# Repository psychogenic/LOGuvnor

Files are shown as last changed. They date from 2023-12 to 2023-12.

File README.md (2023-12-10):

# LO Guv'nor: Si5351 clock generators for the workbench

Copyright (C) 2023  Pat Deegan.  All rights reserved.

[https://psychogenic.com](https://psychogenic.com)

Source code is released under the GPL (see code/LICENSE), hardware resources under CC BY-SA 4.0 (see hardware/LICENSE)

This is a very simple way to transform the widely used Si5351 modules into a useful lab/workbench tool. The entire purpose is to get access to these three clock generators--which can provide clocks in the low kiloHertz up to hundreds of MegaHertz--with minimal interruption to your workflow.
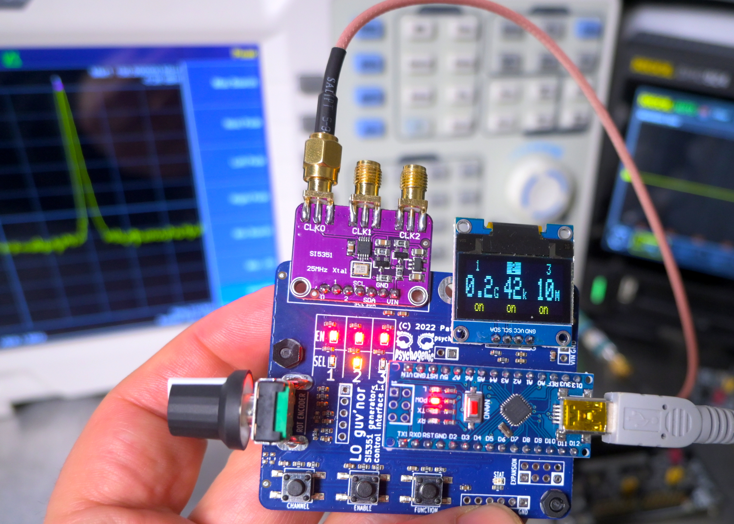
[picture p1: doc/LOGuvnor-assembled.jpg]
LO Guv'nor


A rotary encoder, an OLED display, and a few momentary switches are all glued together through this basic PCB and bundled with a Nano and the code that provides a quick, and hackable, user interface to the clock generator.

This can be used to prototype Si5351 chip/module use, of course, but is mainly meant to provide mid-range clock signals for driving prototypes and tests. Less capable that a true signal generator--it only outputs square waves--but it offers coverage of a wide band of frequency ranges that go beyond what typical (read: inexpensive) function generators can handle.

Most of the intelligence and function of the system resides in the software, which is a bit more involved than the glue hardware.  Full walk-through video, covering the simple hardware, but diving deep into the software created, should be available by December 11th on [youtube](https://youtu.be/oYbZDdBwuf4)

Nothing complex about the schematic, which is little more than
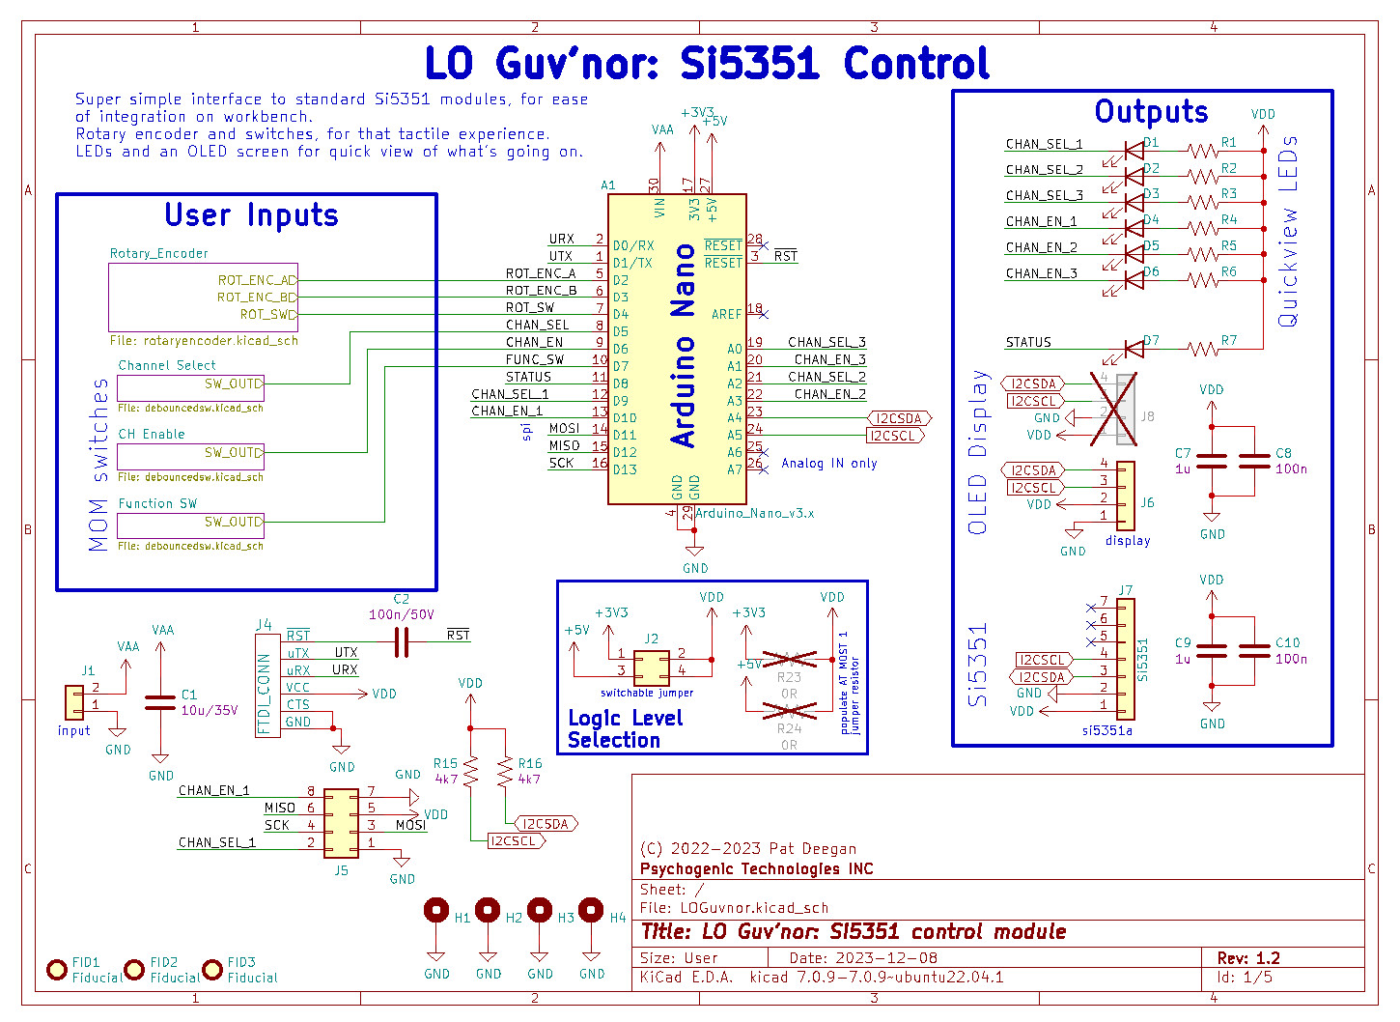
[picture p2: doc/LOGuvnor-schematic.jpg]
LO Guv'nor schematic


The full schema may be found in the [schematic PDF](https://raw.githubusercontent.com/psychogenic/LOGuvnor/main/doc/LOGuvnor-schematic.pdf)

This version of the boards includes some fixes and additional features, which will be covered in future online documentation and video.

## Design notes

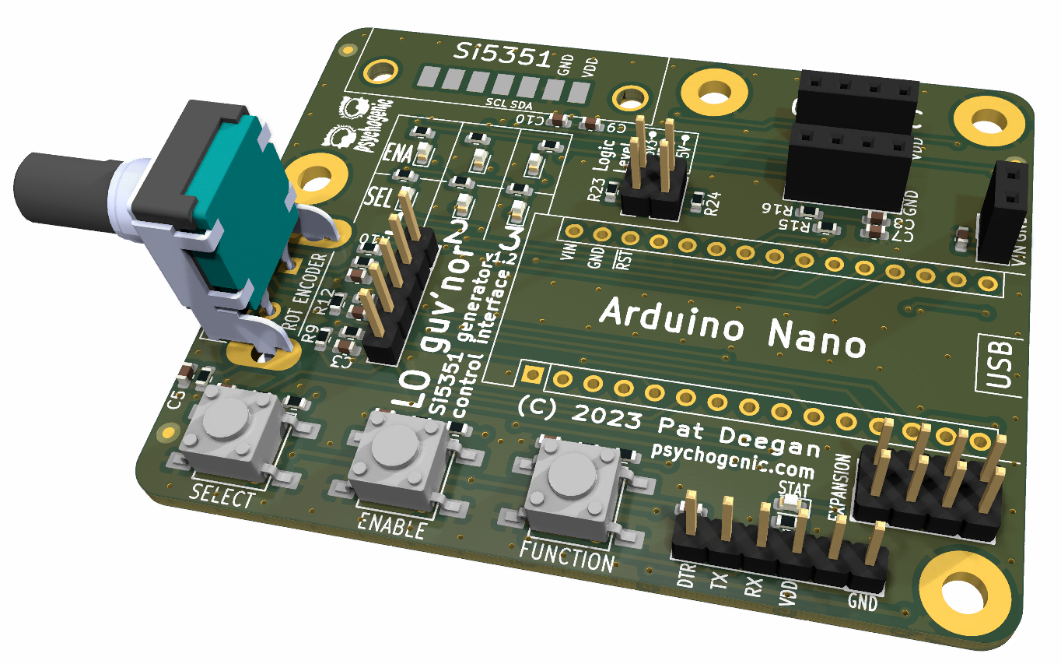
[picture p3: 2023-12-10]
doc/LOGuvnor-PCB.png

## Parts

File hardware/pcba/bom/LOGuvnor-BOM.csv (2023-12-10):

Item | Qty | Reference | DNP | Value | Footprint | Display Value | MPN | Digikey PN
Source: | LOGuvnor/LOGuvnor.kicad_sch
Date: | Sun 10 Dec 2023 03:40:18 AM
Tool: | Eeschema 7.0.9-7.0.9~ubuntu22.04.1
Component Count: | 57
Individual Components:
Item | Qty | Reference | DNP | Value | Footprint | Display Value | MPN | Digikey PN
 |  | A1 |  | Arduino_Nano_v3.x | Module:Arduino_Nano
 |  | C1 |  | C_10u_0603_35V | Capacitor_SMD:C_0603_1608Metric | 10u/35V | GRM188R6YA106MA73D | 490-13248-1-ND
 |  | C2 |  | C_100n_0603_50V | Capacitor_SMD:C_0603_1608Metric | 100n/50V | GCJ188R71H104KA12D | 490-5798-1-ND
 |  | C3 |  | C_100n_0603_50V | Capacitor_SMD:C_0603_1608Metric | 100n/50V | GCJ188R71H104KA12D | 490-5798-1-ND
 |  | C4 |  | C_100n_0603_50V | Capacitor_SMD:C_0603_1608Metric | 100n/50V | GCJ188R71H104KA12D | 490-5798-1-ND
 |  | C5 | DNP | C_10n_0603_100V | Capacitor_SMD:C_0603_1608Metric | 10n/100V | GCM188R72A103KA37J | 490-8028-1-ND
 |  | C6 |  | C_100n_0603_50V | Capacitor_SMD:C_0603_1608Metric | 100n/50V | GCJ188R71H104KA12D | 490-5798-1-ND
 |  | C7 |  | C_1u_0603_50V | Capacitor_SMD:C_0603_1608Metric | 1u | GRT188R61H105KE13D | 490-12330-1-ND
 |  | C8 |  | C_100n_0603_50V | Capacitor_SMD:C_0603_1608Metric | 100n | GCJ188R71H104KA12D | 490-5798-1-ND
 |  | C9 |  | C_1u_0603_50V | Capacitor_SMD:C_0603_1608Metric | 1u | GRT188R61H105KE13D | 490-12330-1-ND
 |  | C10 |  | C_100n_0603_50V | Capacitor_SMD:C_0603_1608Metric | 100n | GCJ188R71H104KA12D | 490-5798-1-ND
 |  | C11 |  | C_100n_0603_50V | Capacitor_SMD:C_0603_1608Metric | 100n/50V | GCJ188R71H104KA12D | 490-5798-1-ND
 |  | C12 |  | C_100n_0603_50V | Capacitor_SMD:C_0603_1608Metric | 100n/50V | GCJ188R71H104KA12D | 490-5798-1-ND
 |  | C13 |  | C_100n_0603_50V | Capacitor_SMD:C_0603_1608Metric | 100n/50V | GCJ188R71H104KA12D | 490-5798-1-ND
 |  | D1 |  | LED | LED_SMD:LED_0603_1608Metric
 |  | D2 |  | LED | LED_SMD:LED_0603_1608Metric
 |  | D3 |  | LED | LED_SMD:LED_0603_1608Metric
 |  | D4 |  | LED | LED_SMD:LED_0603_1608Metric
 |  | D5 |  | LED | LED_SMD:LED_0603_1608Metric
 |  | D6 |  | LED | LED_SMD:LED_0603_1608Metric
 |  | D7 |  | LED | LED_SMD:LED_0603_1608Metric
 |  | J1 |  | Conn_01x02 | Connector_PinSocket_2.54mm:PinSocket_1x02_P2.54mm_Vertical
 |  | J2 |  | Conn_02x02_Odd_Even | Connector_PinHeader_2.54mm:PinHeader_2x02_P2.54mm_Vertical
 |  | J3 | DNP | Conn_01x05 | Connector_PinHeader_2.54mm:PinHeader_1x05_P2.54mm_Vertical
 |  | J4 |  | FTDI_CONN | Connector_PinHeader_2.54mm:PinHeader_1x06_P2.54mm_Vertical
 |  | J5 |  | Conn_02x04_Odd_Even | Connector_PinHeader_2.54mm:PinHeader_2x04_P2.54mm_Vertical
 |  | J6 |  | Conn_01x04 | Connector_PinSocket_2.54mm:PinSocket_1x04_P2.54mm_Vertical
 |  | J7 |  | Si5351 | psychogenic:Si5351aModule
 |  | J8 | DNP | Conn_01x04 | Connector_PinSocket_2.54mm:PinSocket_1x04_P2.54mm_Vertical
 |  | R1 |  | R_1k_0603 | Resistor_SMD:R_0603_1608Metric | 1k | CRGP0603F1K0 | A130416CT-ND
 |  | R2 |  | R_1k_0603 | Resistor_SMD:R_0603_1608Metric | 1k | CRGP0603F1K0 | A130416CT-ND
 |  | R3 |  | R_1k_0603 | Resistor_SMD:R_0603_1608Metric | 1k | CRGP0603F1K0 | A130416CT-ND
 |  | R4 |  | R_1k_0603 | Resistor_SMD:R_0603_1608Metric | 1k | CRGP0603F1K0 | A130416CT-ND
 |  | R5 |  | R_1k_0603 | Resistor_SMD:R_0603_1608Metric | 1k | CRGP0603F1K0 | A130416CT-ND
 |  | R6 |  | R_1k_0603 | Resistor_SMD:R_0603_1608Metric | 1k | CRGP0603F1K0 | A130416CT-ND
 |  | R7 |  | R_1k_0603 | Resistor_SMD:R_0603_1608Metric | 1k | CRGP0603F1K0 | A130416CT-ND
 |  | R8 |  | R_10k_0603 | Resistor_SMD:R_0603_1608Metric | 10k | CRGP0603F10K | A130428CT-ND
 |  | R9 |  | R_10k_0603 | Resistor_SMD:R_0603_1608Metric | 10k | CRGP0603F10K | A130428CT-ND
 |  | R10 |  | R_10k_0603 | Resistor_SMD:R_0603_1608Metric | 10k | CRGP0603F10K | A130428CT-ND
 |  | R11 |  | R_1k_0603 | Resistor_SMD:R_0603_1608Metric | 1k | CRGP0603F1K0 | A130416CT-ND
 |  | R12 |  | R_10k_0603 | Resistor_SMD:R_0603_1608Metric | 10k | CRGP0603F10K | A130428CT-ND
 |  | R13 |  | R_10k_0603 | Resistor_SMD:R_0603_1608Metric | 10k | CRGP0603F10K | A130428CT-ND
 |  | R14 | DNP | R_1M_0603 | Resistor_SMD:R_0603_1608Metric | 1M | CRGCQ0603F1M0 | A129724CT-ND
 |  | R15 |  | R_4k7_0603 | Resistor_SMD:R_0603_1608Metric | 4k7 | CRGP0603F4K7 | A130424DKR-ND
 |  | R16 |  | R_4k7_0603 | Resistor_SMD:R_0603_1608Metric | 4k7 | CRGP0603F4K7 | A130424DKR-ND
 |  | R17 |  | R_10k_0603 | Resistor_SMD:R_0603_1608Metric | 10k | CRGP0603F10K | A130428CT-ND
 |  | R18 |  | R_1k_0603 | Resistor_SMD:R_0603_1608Metric | 1k | CRGP0603F1K0 | A130416CT-ND
 |  | R19 |  | R_10k_0603 | Resistor_SMD:R_0603_1608Metric | 10k | CRGP0603F10K | A130428CT-ND
 |  | R20 |  | R_1k_0603 | Resistor_SMD:R_0603_1608Metric | 1k | CRGP0603F1K0 | A130416CT-ND
 |  | R21 |  | R_10k_0603 | Resistor_SMD:R_0603_1608Metric | 10k | CRGP0603F10K | A130428CT-ND
 |  | R22 |  | R_1k_0603 | Resistor_SMD:R_0603_1608Metric | 1k | CRGP0603F1K0 | A130416CT-ND
 |  | R23 | DNP | R_0R_0603_JUMPER | Resistor_SMD:R_0603_1608Metric | 0R | CRG0603ZR | A106051CT-ND
 |  | R24 | DNP | R_0R_0603_JUMPER | Resistor_SMD:R_0603_1608Metric | 0R | CRG0603ZR | A106051CT-ND
 |  | S1 |  | PEC12R-2220F-S0024 | psysnapeda:XDCR_PEC12R-2220F-S0024 |  | PEC12R-2220F-S0024 | PEC12R-2220F-S0024-ND
 |  | SW1 |  | SW_Push_6x6 | flyingcarsfootprints:FSM2JSMA-6x6mm-SWITCH | SW_Push | FSM2JSMA | 450-1130-ND
 |  | SW2 |  | SW_Push_6x6 | flyingcarsfootprints:FSM2JSMA-6x6mm-SWITCH | SW_Push | FSM2JSMA | 450-1130-ND
 |  | SW3 |  | SW_Push_6x6 | flyingcarsfootprints:FSM2JSMA-6x6mm-SWITCH | SW_Push | FSM2JSMA | 450-1130-ND
Collated Components:
Item | Qty | Reference | DNP | Value | Footprint | Display Value | MPN | Digikey PN
1 | 1 | A1 | 0 | Arduino_Nano_v3.x | Module:Arduino_Nano
2 | 1 | C1 | 0 | C_10u_0603_35V | Capacitor_SMD:C_0603_1608Metric | 10u/35V | GRM188R6YA106MA73D | 490-13248-1-ND
3 | 9 | C2,C3,C4,C6,C8,C10,C11,C12,C13 | 0 | C_100n_0603_50V | Capacitor_SMD:C_0603_1608Metric | 100n/50V | GCJ188R71H104KA12D | 490-5798-1-ND
4 | 0 | C5 | DNPs: all DNP, final qty: 0 | C_10n_0603_100V | Capacitor_SMD:C_0603_1608Metric | 10n/100V | GCM188R72A103KA37J | 490-8028-1-ND
5 | 2 | C7,C9 | 0 | C_1u_0603_50V | Capacitor_SMD:C_0603_1608Metric | 1u | GRT188R61H105KE13D | 490-12330-1-ND
6 | 7 | D1,D2,D3,D4,D5,D6,D7 | 0 | LED | LED_SMD:LED_0603_1608Metric
7 | 1 | J1 | 0 | Conn_01x02 | Connector_PinSocket_2.54mm:PinSocket_1x02_P2.54mm_Vertical
8 | 1 | J2 | 0 | Conn_02x02_Odd_Even | Connector_PinHeader_2.54mm:PinHeader_2x02_P2.54mm_Vertical
9 | 0 | J3 | DNPs: all DNP, final qty: 0 | Conn_01x05 | Connector_PinHeader_2.54mm:PinHeader_1x05_P2.54mm_Vertical
10 | 1 | J4 | 0 | FTDI_CONN | Connector_PinHeader_2.54mm:PinHeader_1x06_P2.54mm_Vertical
11 | 1 | J5 | 0 | Conn_02x04_Odd_Even | Connector_PinHeader_2.54mm:PinHeader_2x04_P2.54mm_Vertical
12 | 1 | J6,J8 | DNPs: 1 (final qty: 1): J8 | Conn_01x04 | Connector_PinSocket_2.54mm:PinSocket_1x04_P2.54mm_Vertical
13 | 1 | J7 | 0 | Si5351 | psychogenic:Si5351aModule
14 | 11 | R1,R2,R3,R4,R5,R6,R7,R11,R18,R20,R22 | 0 | R_1k_0603 | Resistor_SMD:R_0603_1608Metric | 1k | CRGP0603F1K0 | A130416CT-ND
15 | 8 | R8,R9,R10,R12,R13,R17,R19,R21 | 0 | R_10k_0603 | Resistor_SMD:R_0603_1608Metric | 10k | CRGP0603F10K | A130428CT-ND
16 | 0 | R14 | DNPs: all DNP, final qty: 0 | R_1M_0603 | Resistor_SMD:R_0603_1608Metric | 1M | CRGCQ0603F1M0 | A129724CT-ND
17 | 2 | R15,R16 | 0 | R_4k7_0603 | Resistor_SMD:R_0603_1608Metric | 4k7 | CRGP0603F4K7 | A130424DKR-ND
18 | 0 | R23,R24 | DNPs: all DNP, final qty: 0 | R_0R_0603_JUMPER | Resistor_SMD:R_0603_1608Metric | 0R | CRG0603ZR | A106051CT-ND
19 | 1 | S1 | 0 | PEC12R-2220F-S0024 | psysnapeda:XDCR_PEC12R-2220F-S0024 |  | PEC12R-2220F-S0024 | PEC12R-2220F-S0024-ND
20 | 3 | SW1,SW2,SW3 | 0 | SW_Push_6x6 | flyingcarsfootprints:FSM2JSMA-6x6mm-SWITCH | SW_Push | FSM2JSMA | 450-1130-ND

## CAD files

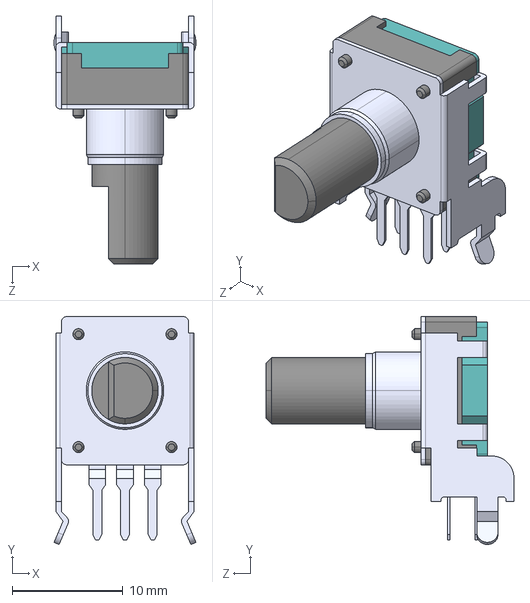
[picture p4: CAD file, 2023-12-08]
hardware/3dmodels/PEC12R-2220F-S0024.step
12.8 x 20.6 x 22.4 mm

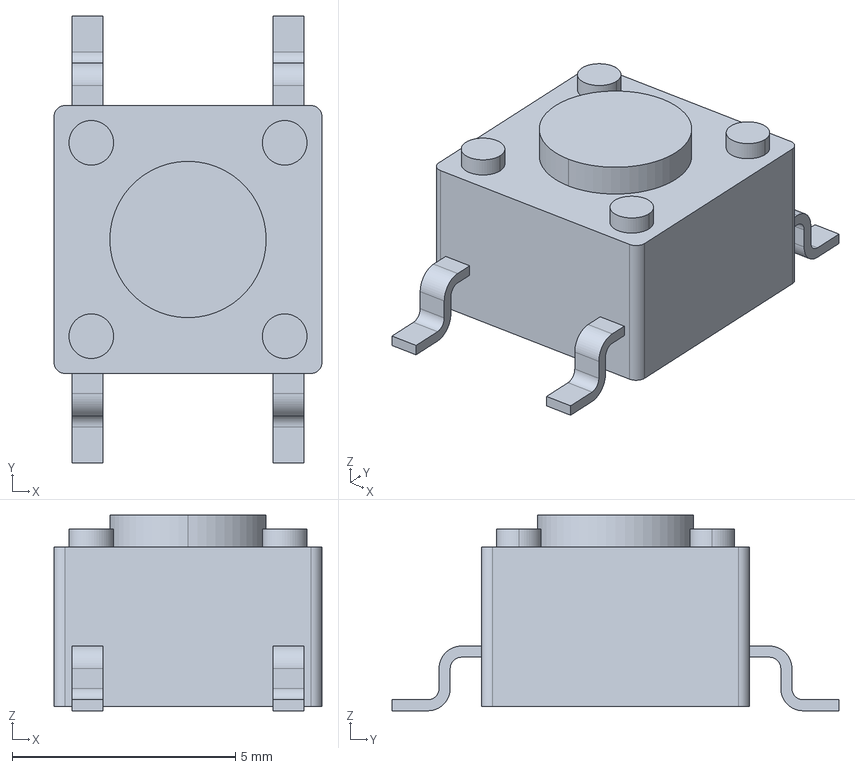
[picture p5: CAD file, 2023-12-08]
hardware/3dmodels/FSM2JSMA.step
6.00 x 10.0 x 4.38 mm

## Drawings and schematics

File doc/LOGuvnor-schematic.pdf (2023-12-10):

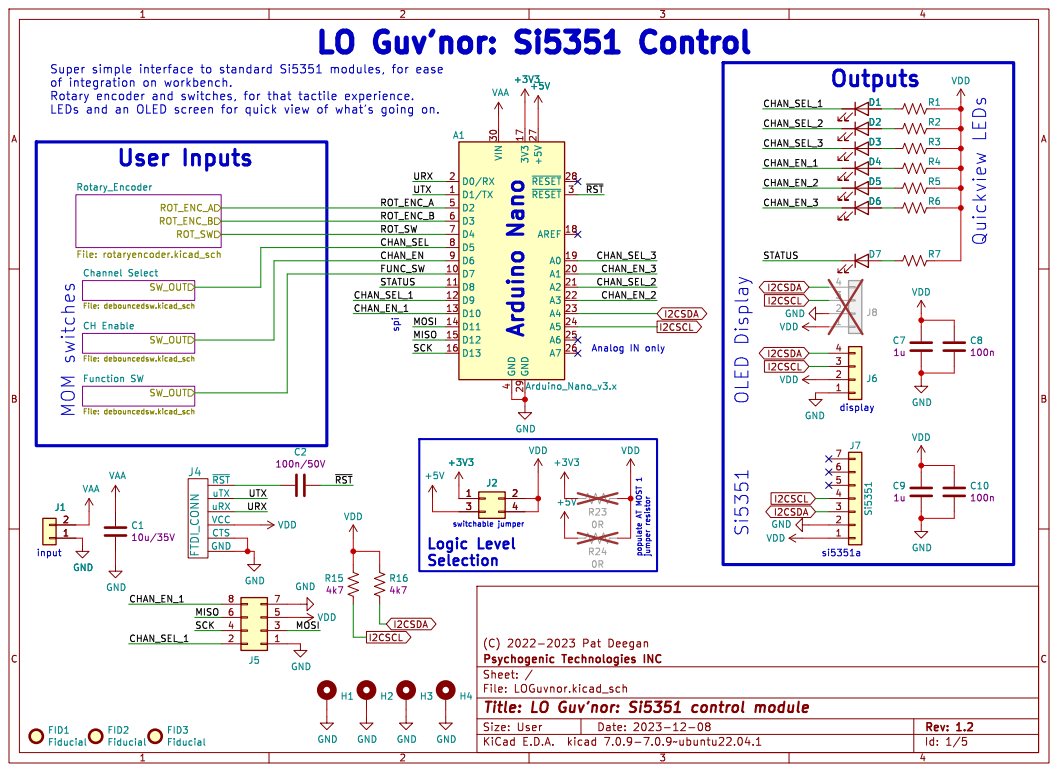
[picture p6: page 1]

+5V +3V3 GND
LEDs and an OLED screen for quick view of what's going on.

of integration on workbench.

File: debouncedsw.kicad_sch SW_OUT CH Enable

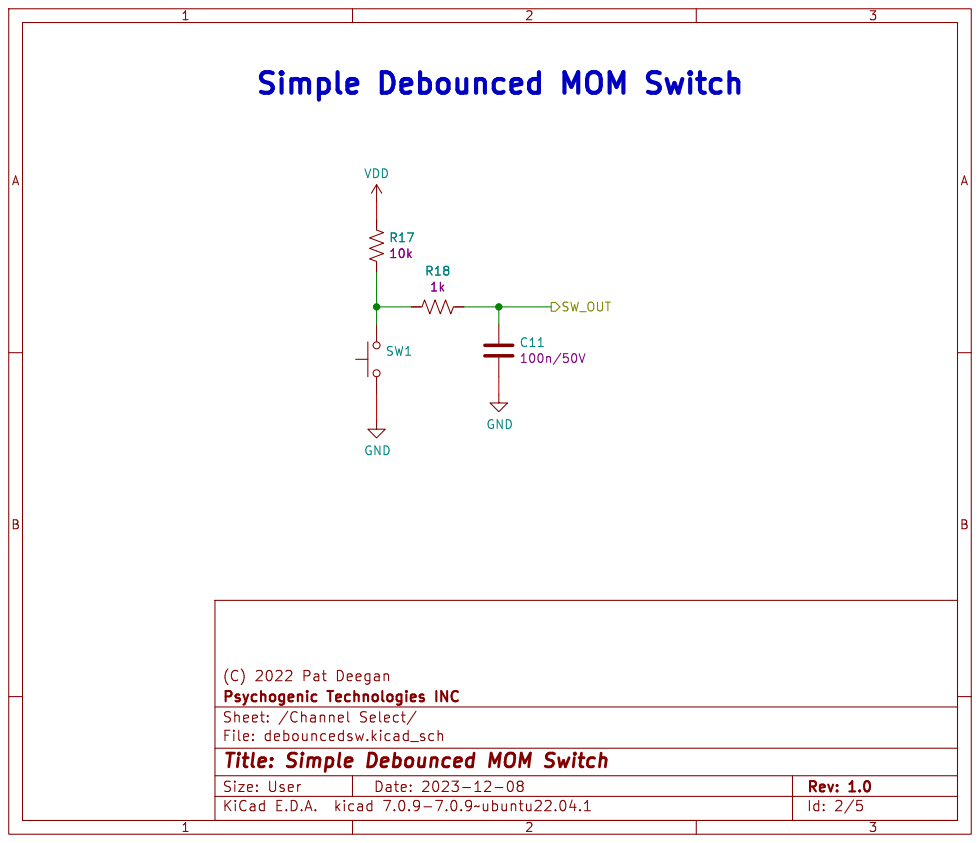
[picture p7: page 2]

Id: 2/5 Title: Simple Debounced MOM Switch

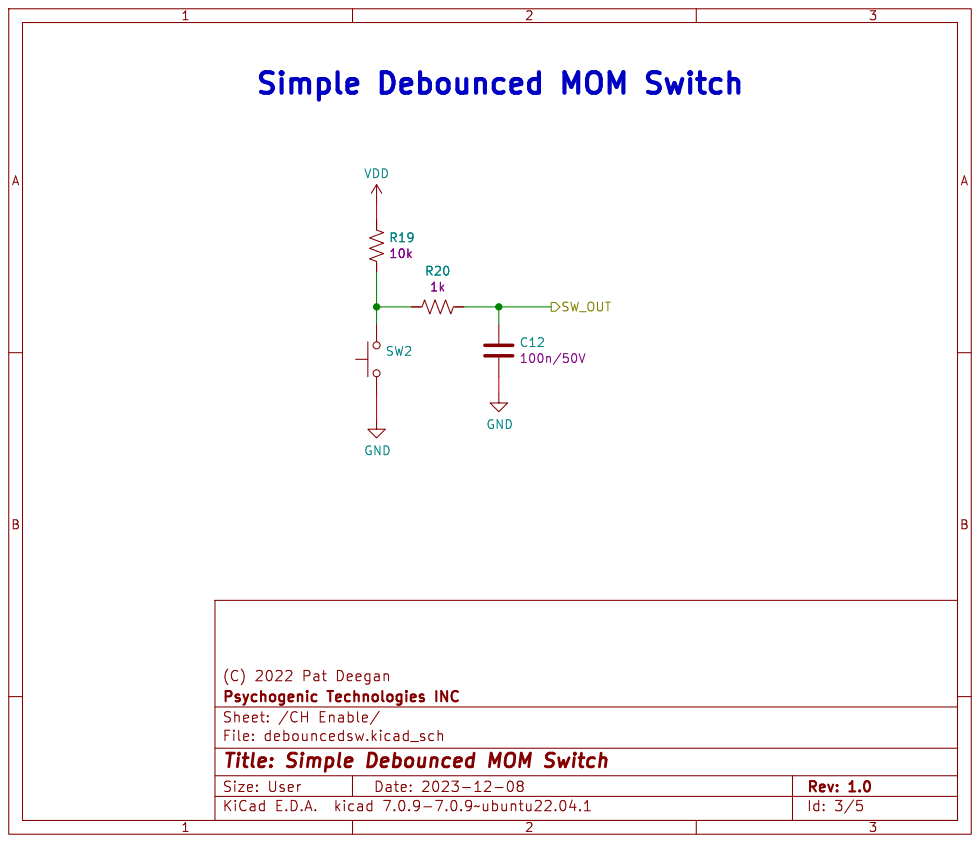
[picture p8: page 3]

Id: 3/5 Title: Simple Debounced MOM Switch

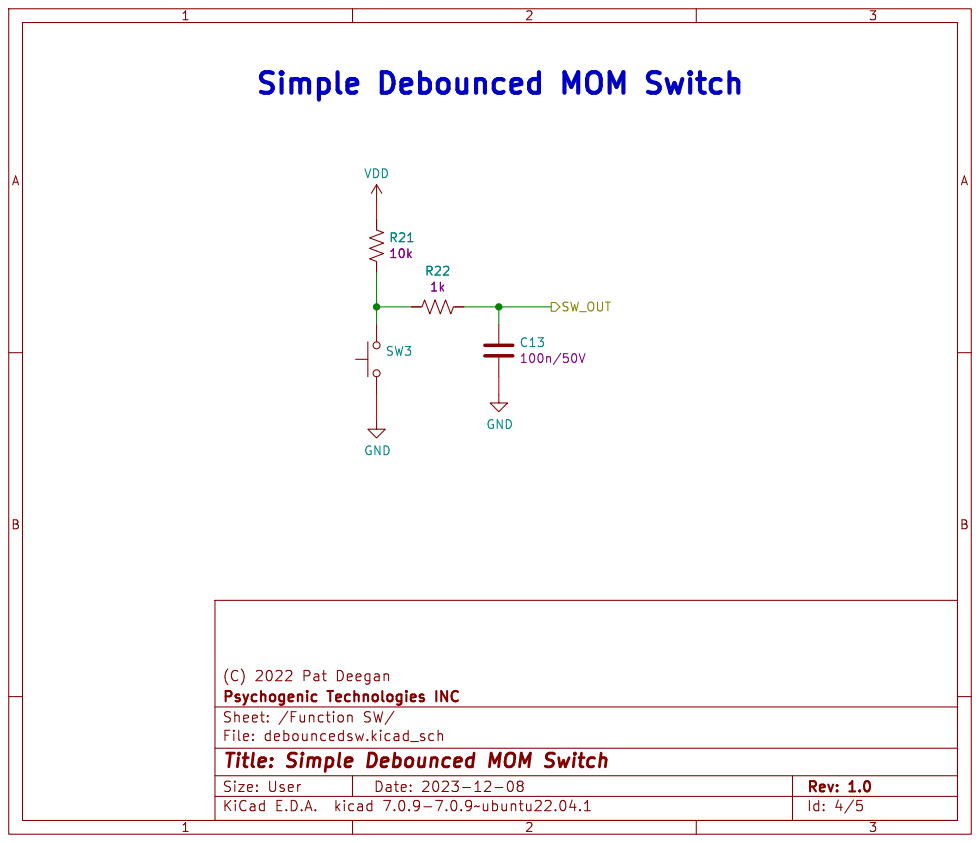
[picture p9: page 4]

Id: 4/5 Title: Simple Debounced MOM Switch

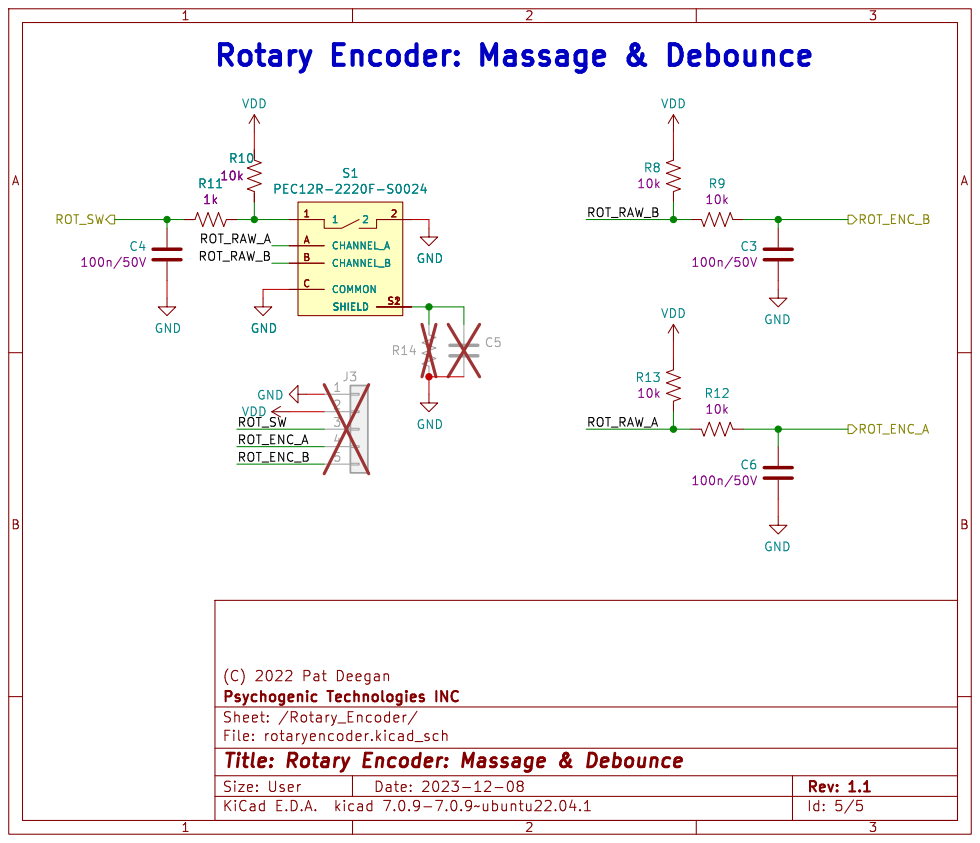
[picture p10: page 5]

File: rotaryencoder.kicad_sch Sheet: /Rotary_Encoder/
Id: 5/5 Title: Rotary Encoder: Massage & Debounce

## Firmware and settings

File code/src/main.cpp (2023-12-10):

/*
 * LOGuvnorDriver.ino, part of the LOGuvnor project
 *
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
 *  This is the main driver for the LOGuvnor library.
 *
 *  It's only jobs are to:
 *    * setup the various pins in use (as inputs outputs etc)
 *    * construct the rotary encoder object used and set that up
 *    * init the library Driver object
 *    * loop around, noticing if knob was turned (and telling the world) and ticking driver
 *
 * The end.
 *
 *
 */



#ifdef DESKTOP_BUILD2
/*
 * LOGuvnorDriver.ino, part of the LOGuvnor project
 *
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
 *  This is the main driver for the LOGuvnor library.
 *
 *  It's only jobs are to:
 *    * setup the various pins in use (as inputs outputs etc)
 *    * construct the rotary encoder object used and set that up
 *    * init the library Driver object
 *    * loop around, noticing if knob was turned (and telling the world) and ticking driver
 *
 * The end.
 *
 *
 */

#include <LOGuvnor.h>
#include <RotaryEncoder.h>



/* *** Rotary encoder stuff... *** */

// create the instance
// use TWO03 mode when A and B signals are both LOW or HIGH in latch position.
RotaryEncoder rotEnc(PIN_ROTENC_A, PIN_ROTENC_B, RotaryEncoder::LatchMode::FOUR3);

// give it an ISR and flag
volatile bool checkRotaryEncoder = false;
void checkPosition()
{
  rotEnc.tick(); // just call tick() to check the state.
  checkRotaryEncoder = true;
}



/* *** setup *** */
void setup() {
	uint8_t inputs[] = {
			PIN_ROTENC_A,
			PIN_ROTENC_B,
			PIN_ROTSWITCH,
			PIN_SW_CHANSEL,
			PIN_SW_CHANEN,
			PIN_SW_FUNCTION,
			0xff
	};
	uint8_t outputs[] = {
			PIN_STATUS,
			PIN_INDIC_nCHANSEL_1,
			PIN_INDIC_nCHANENA_1,
			PIN_INDIC_nCHANSEL_2,
			PIN_INDIC_nCHANENA_2,
			PIN_INDIC_nCHANSEL_3,
			PIN_INDIC_nCHANENA_3,
			0xff
	};


	uint8_t i=0;
	while (inputs[i] != 0xff) {
		pinMode(inputs[i], INPUT); //_PULLUP);
		i++;
	}
	i=0;
	while (outputs[i] != 0xff) {
		pinMode(outputs[i], OUTPUT);
		digitalWrite(outputs[i], HIGH);
    i++;
	}

/*
  for (uint8_t i=0; i<10; i++) {

    digitalWrite(PIN_INDIC_nCHANENA_1, HIGH);
    delay(200);
    digitalWrite(PIN_INDIC_nCHANENA_1, LOW);
    delay(200);

  }
*/

	// register interrupt routine
	attachInterrupt(digitalPinToInterrupt(PIN_ROTENC_A), checkPosition, CHANGE);
	attachInterrupt(digitalPinToInterrupt(PIN_ROTENC_B), checkPosition, CHANGE);

	LOGuvnor::Driver & LOGuv = LOGuvnor::Globals::driver();
	LOGuv.begin();


}

/* *** main loop *** */
void loop() {
	// if encoder saw action, tell the driver
	if (checkRotaryEncoder) {
		checkRotaryEncoder = false;
		LOGuvnor::Globals::driver().positionChangeEvent(rotEnc.getPosition());
	}

	// always tick the driver to keep it alive and
	// doing what it does
	LOGuvnor::Globals::driver().tick();
}




#endif

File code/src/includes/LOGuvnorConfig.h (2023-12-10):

/*
 * LOGuvnorConfig.h
 *
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
*     You should have received a copy of the GNU General Public License along 
*     with LOGuvnor. If not, see <https://www.gnu.org/licenses/>.
 */

#ifndef SRC_LOGUVNORCONFIG_H_
#define SRC_LOGUVNORCONFIG_H_

/* default frequencies per channel, in Hz */
#define FREQUENCY_DEFAULT_CHANNEL_1			7500
#define FREQUENCY_DEFAULT_CHANNEL_2			42000
#define FREQUENCY_DEFAULT_CHANNEL_3			10000000ULL

/* if the digit selection seems unnatural/to go the
 * wrong way, uncomment this define and it'll flip it.
 */
//#define FREQEDIT_DIGITSELECTKNOB_INVERT

/*
 * In development, may want to comment out
 * DIE_ON_SIGGEN_ERROR
 * When defined, will flash status if problem
 * bringing up si5351
 */
#define DIE_ON_SIGGEN_ERROR

#define STATUS_LED_ON_DURING_OPERATION		false /* true or false */
#define STATUS_LED_HEARTBEAT_TICKPERIOD		100 /* smaller is faster */


#define SI5351_CORRECTIONFACTOR		-1245 /* tested deviation @ 10MHz */
#define SI5351_DRIVESTRENGTH		SI5351_DRIVE_4MA /* from library 2,4,6 or 8mA*/

// TOO FAT: define ENABLE_DEBUG_MESSAGES

/* Scrolling text: a luxury... if you really need some room,
 * save over two hundred bytes by disabling this define
 */
#define ENABLE_SCROLLERS

/* DEBUG_SERIAL_BAUDRATE
 * undef to disable serial debug
 */
#define DEBUG_SERIAL_BAUDRATE	157200

#define SI5351_NUM_CHANNELS		3

#define ERROR_MESSAGEFLASH_MS	700

#define FREQUENCY_MINIMUM_HZ	1000 /* 2000 */
#define FREQUENCY_MAXIMUM_HZ	230000000ULL


#define SCREEN_WIDTH 		128 // OLED display width, in pixels
#define SCREEN_HEIGHT 		32 // OLED display height, in pixels
#define OLED_RESET     		-1 		// Reset pin # (or -1 if sharing Arduino reset pin)
#define SCREEN_ADDRESS 		0x3C 	///< See datasheet for Address; 0x3D for 128x64, 0x3C for 128x32


#endif /* SRC_LOGUVNORCONFIG_H_ */

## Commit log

2023-12-08 Initial hardware import, v1.0
    [FSM2JSMA.step, LOGuvnor.kicad_pcb, LOGuvnor.kicad_sch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]
2023-12-10 v1.2: fixes for vdd and a6/a7 pins
    [LOGuvnor.kicad_pcb, LOGuvnor.kicad_sch, debouncedsw.kicad_sch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]
2023-12-10 updated to recent stitch footprint to keep from BOM etc with attribs
    [LOGuvnor.kicad_pcb]
2023-12-10 Added BOM
    [LOGuvnor-BOM.csv, debouncedsw.kicad_sch]

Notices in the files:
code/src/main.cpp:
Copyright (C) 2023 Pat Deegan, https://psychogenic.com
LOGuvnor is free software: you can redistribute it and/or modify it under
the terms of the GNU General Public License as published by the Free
